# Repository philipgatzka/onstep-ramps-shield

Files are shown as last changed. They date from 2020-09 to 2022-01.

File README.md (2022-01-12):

# onstep-ramps-shield

This is an add-on board for a RAMPSv1.4 (and some later versions) board, which
carries a bit of additional hardware necessary for an
[OnStep](https://github.com/hjd1964/OnStep)
telescope controller.

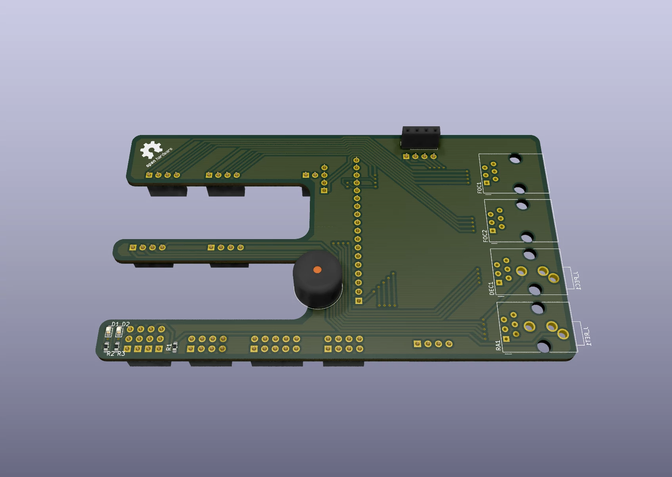
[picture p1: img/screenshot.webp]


There are different ways to build an OnStep, including using a completely custom
board, but I liked the modular approach and used an Arduino Mega in combination
with a RAMPS shield. The custom boards of course offer places to fit connectors
and such which the Arduino/RAMPS combination doesn't, so I'm trying to build
this board to help with that.

At the moment, the board takes the following components:
- RA motor connector, RJ12 6p6c
- DEC motor connector, RJ12 6p6c
- Focuser motor 1 connector, RJ12 6p6c
- Focuser motor 2 connector, RJ12 6p6c
- (Polar alignment scope illuminator connector, 3-Pin 3.5mm audio jack)
- (PEC sensor connector, 3-Pin 3.5mm audio jack)
- Buzzer
- DS3231 RTC via I2C
- BME280 environmental sensor via I2C
- HC05 Bluetooth module via Serial

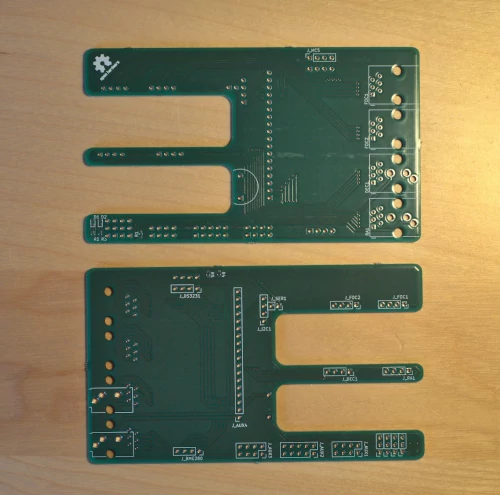
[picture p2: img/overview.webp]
overview


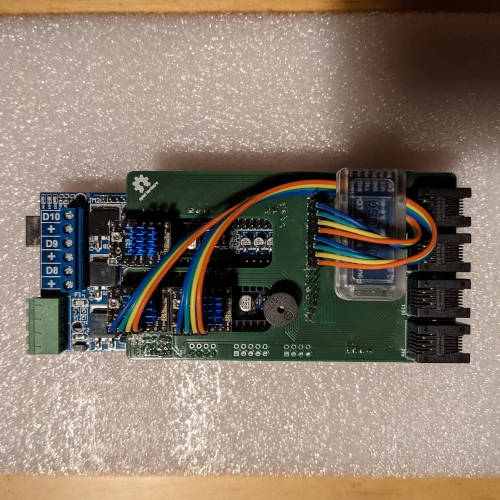
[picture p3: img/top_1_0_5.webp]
top_1_0_5


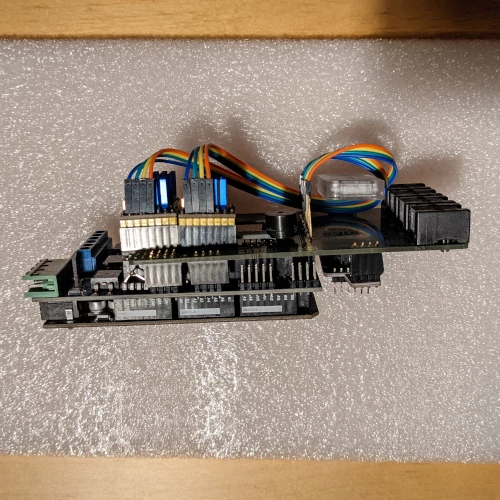
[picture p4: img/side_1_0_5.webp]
side_1_0_5


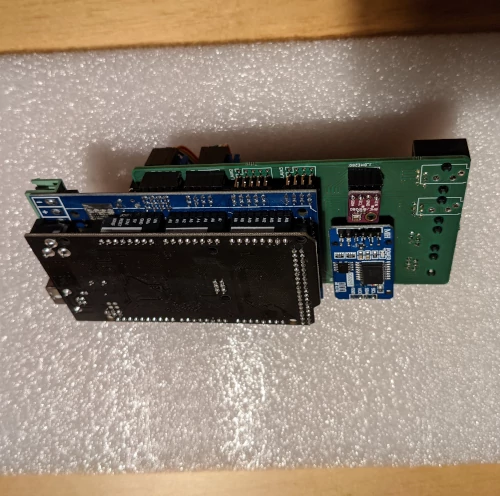
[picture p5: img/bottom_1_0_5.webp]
bottom_1_0_5


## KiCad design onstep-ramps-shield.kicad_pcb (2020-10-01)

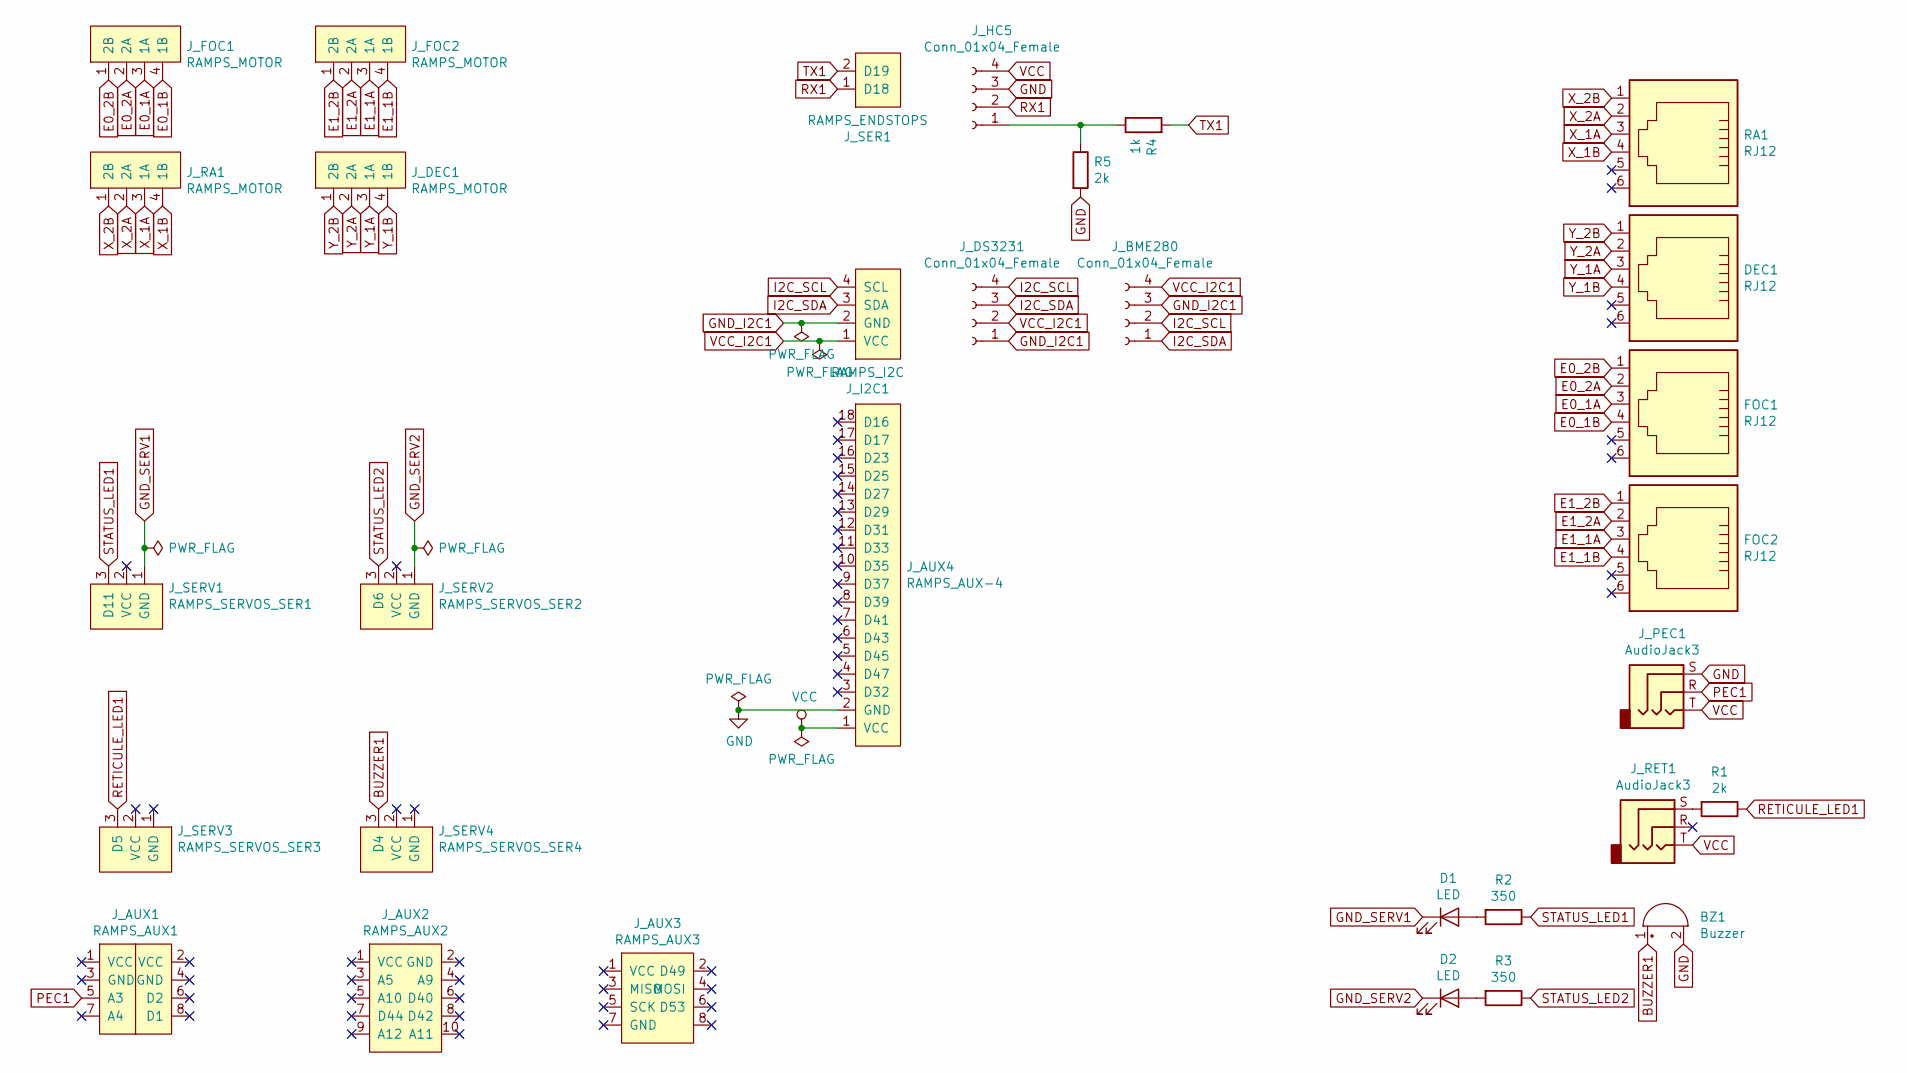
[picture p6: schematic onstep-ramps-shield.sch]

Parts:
BZ1: Buzzer; Buzzer_12x9.5RM7.6
D1, D2: LED; LED_0603_1608Metric_Pad1.05x0.95mm_HandSolder
DEC1: RJ12; RJ12_Amphenol_54601
FOC1, FOC2: RJ12; RJ12_Amphenol_54601
J_AUX1: RAMPS_AUX1; PinSocket_2x04_P2.54mm_Vertical
J_AUX2: RAMPS_AUX2; PinSocket_2x05_P2.54mm_Vertical
J_AUX3: RAMPS_AUX3; PinSocket_2x04_P2.54mm_Vertical
J_AUX4: RAMPS_AUX-4; PinSocket_1x18_P2.54mm_Vertical
J_BME280: Conn_01x04_Female; PinSocket_1x04_P2.54mm_Vertical
J_DEC1: RAMPS_MOTOR; PinSocket_1x04_P2.54mm_Vertical
J_DS3231: Conn_01x04_Female; PinSocket_1x04_P2.54mm_Vertical
J_FOC1, J_FOC2: RAMPS_MOTOR; PinSocket_1x04_P2.54mm_Vertical
J_HC5: Conn_01x04_Female; PinSocket_1x04_P2.54mm_Vertical
J_I2C1: RAMPS_I2C; PinSocket_1x04_P2.54mm_Vertical
J_PEC1: AudioJack3; Jack_3.5mm_CUI_SJ1-3533NG_Horizontal_CircularHoles
J_RA1: RAMPS_MOTOR; PinSocket_1x04_P2.54mm_Vertical
J_RET1: AudioJack3; Jack_3.5mm_CUI_SJ1-3533NG_Horizontal_CircularHoles
J_SER1: RAMPS_ENDSTOPS; PinSocket_1x02_P2.54mm_Vertical
J_SERV1: RAMPS_SERVOS_SER1; PinSocket_1x03_P2.54mm_Vertical
J_SERV2: RAMPS_SERVOS_SER2; PinSocket_1x03_P2.54mm_Vertical
J_SERV3: RAMPS_SERVOS_SER3; PinSocket_1x03_P2.54mm_Vertical
J_SERV4: RAMPS_SERVOS_SER4; PinSocket_1x03_P2.54mm_Vertical
R1, R5: 2k; R_0603_1608Metric_Pad1.05x0.95mm_HandSolder
R2, R3: 350; R_0603_1608Metric_Pad1.05x0.95mm_HandSolder
R4: 1k; R_0603_1608Metric_Pad1.05x0.95mm_HandSolder
RA1: RJ12; RJ12_Amphenol_54601

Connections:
BUZZER1: BZ1.1 (-), J_SERV4.3 (D4)
E0_1A: FOC1.3, J_FOC1.3 (1A)
E0_1B: FOC1.4, J_FOC1.4 (1B)
E0_2A: FOC1.2, J_FOC1.2 (2A)
E0_2B: FOC1.1, J_FOC1.1 (2B)
E1_1A: FOC2.3, J_FOC2.3 (1A)
E1_1B: FOC2.4, J_FOC2.4 (1B)
E1_2A: FOC2.2, J_FOC2.2 (2A)
E1_2B: FOC2.1, J_FOC2.1 (2B)
GND: BZ1.2 (+), J_AUX4.2 (GND), J_HC5.3, J_PEC1.S, R5.2
GND_I2C1: J_BME280.3, J_DS3231.1, J_I2C1.2 (GND)
GND_SERV1: D1.1 (K), J_SERV1.1 (GND)
GND_SERV2: D2.1 (K), J_SERV2.1 (GND)
I2C_SCL: J_BME280.2, J_DS3231.4, J_I2C1.4 (SCL)
I2C_SDA: J_BME280.1, J_DS3231.3, J_I2C1.3 (SDA)
unnamed: D1.2 (A), R2.2
unnamed: D2.2 (A), R3.2
unnamed: J_HC5.1, R4.1, R5.1
unnamed: J_RET1.S, R1.2
PEC1: J_AUX1.5 (A3), J_PEC1.R
RETICULE_LED1: J_SERV3.3 (D5), R1.1
RX1: J_HC5.2, J_SER1.1 (D18)
STATUS_LED1: J_SERV1.3 (D11), R2.1
STATUS_LED2: J_SERV2.3 (D6), R3.1
TX1: J_SER1.2 (D19), R4.2
VCC: J_AUX4.1 (VCC), J_HC5.4, J_PEC1.T, J_RET1.T
VCC_I2C1: J_BME280.4, J_DS3231.2, J_I2C1.1 (VCC)
X_1A: J_RA1.3 (1A), RA1.3
X_1B: J_RA1.4 (1B), RA1.4
X_2A: J_RA1.2 (2A), RA1.2
X_2B: J_RA1.1 (2B), RA1.1
Y_1A: DEC1.3, J_DEC1.3 (1A)
Y_1B: DEC1.4, J_DEC1.4 (1B)
Y_2A: DEC1.2, J_DEC1.2 (2A)
Y_2B: DEC1.1, J_DEC1.1 (2B)

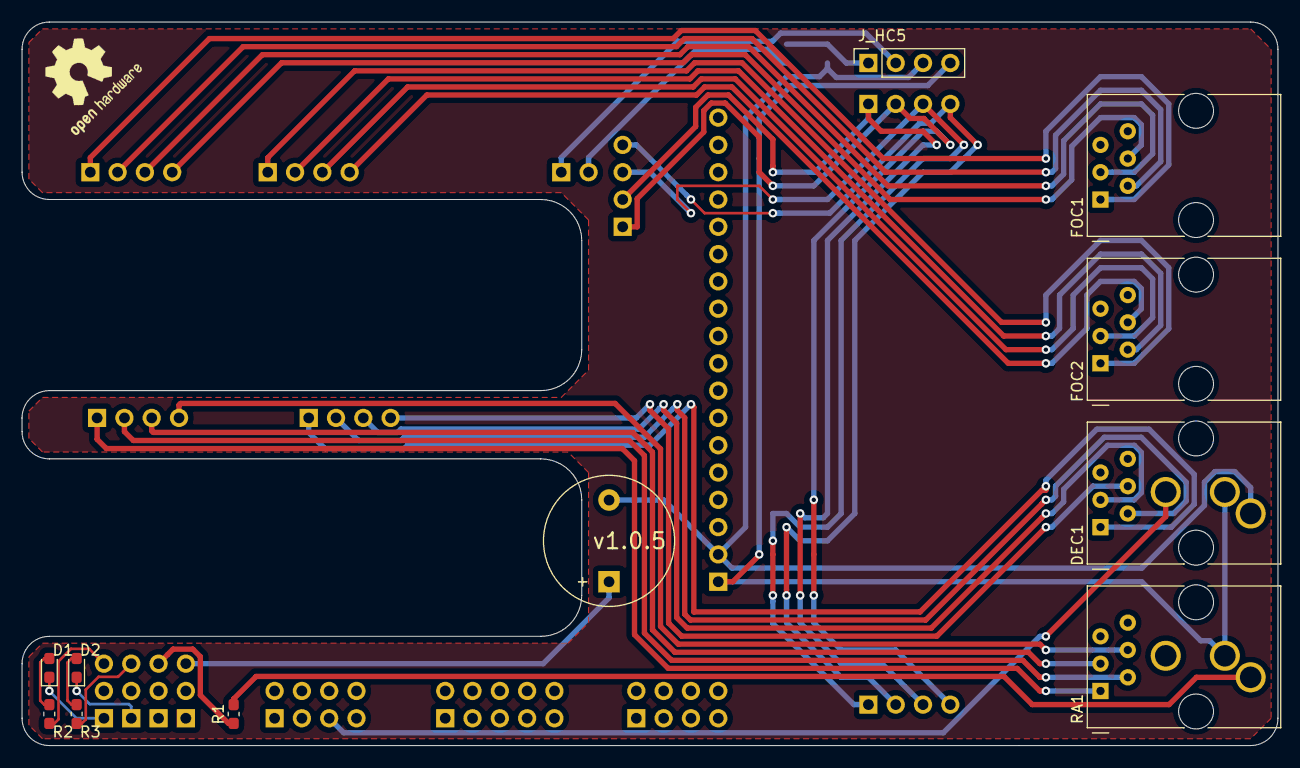
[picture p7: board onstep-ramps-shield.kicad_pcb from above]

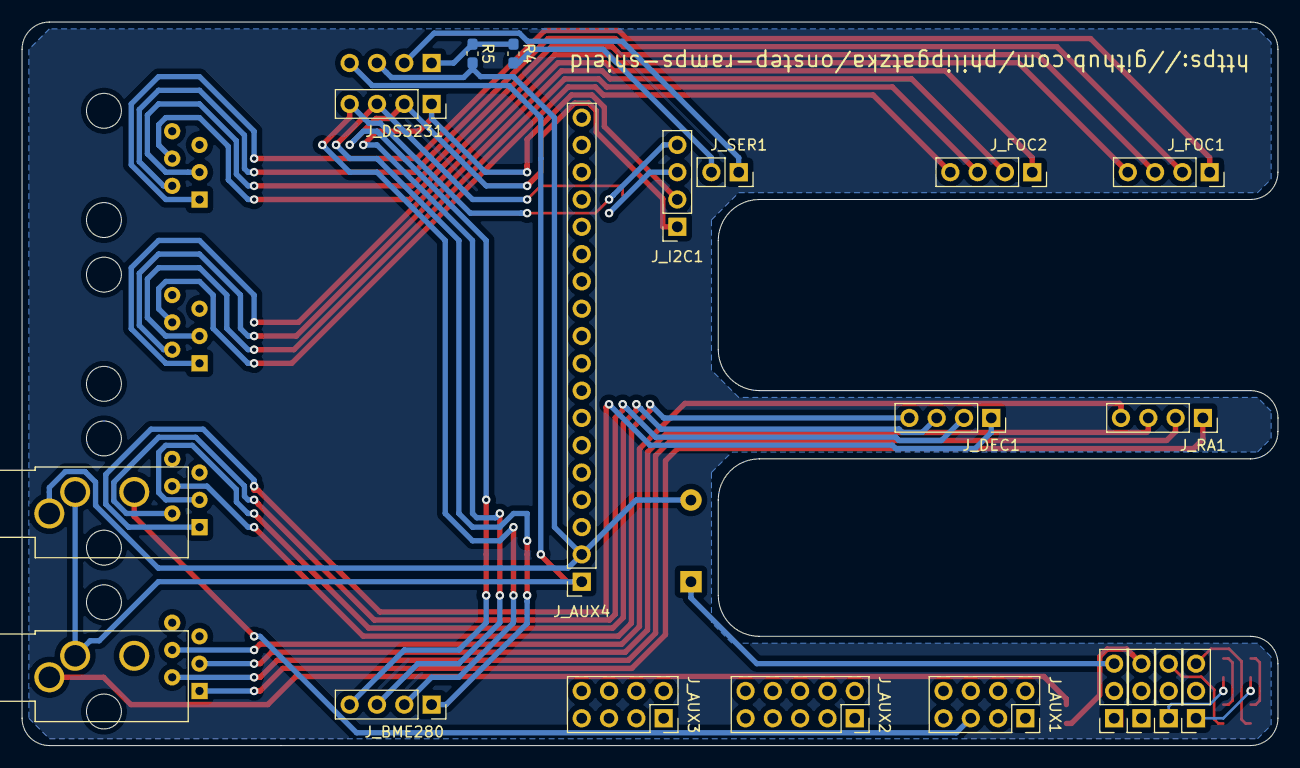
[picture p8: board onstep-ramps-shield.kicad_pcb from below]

Board: 2 copper layers, 116.8 x 67.3 mm, 31 parts (20 on the bottom side), 35 nets.

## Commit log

2020-08-31 KiCad init
    [onstep-ramps-shield.kicad_pcb, onstep-ramps-shield.sch]
2020-08-31 Add RAMPS connectors to project library
2020-08-31 Schematic, initial board layout
    [onstep-ramps-shield.kicad_pcb, onstep-ramps-shield.sch]
2020-08-31 WIP - Routing
    [onstep-ramps-shield.kicad_pcb]
2020-09-03 Include HC05
    [onstep-ramps-shield.kicad_pcb, onstep-ramps-shield.sch]
2020-09-05 Measured distances
    [onstep-ramps-shield.kicad_pcb]
2020-09-05 Reorder components
    [onstep-ramps-shield.kicad_pcb, onstep-ramps-shield.sch]
2020-09-05 Copper fill
    [onstep-ramps-shield.kicad_pcb]
2020-09-05 Increase inner corner radius
    [onstep-ramps-shield.kicad_pcb]
2020-09-05 Remove gerbers
    [onstep-ramps-shield-B_Mask.gbr, onstep-ramps-shield-B_Paste.gbr, onstep-ramps-shield-B_SilkS.gbr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]
2020-09-05 Add .gitignore for gerber files
2020-09-05 Update connectors
    [onstep-ramps-shield.kicad_pcb, onstep-ramps-shield.sch]
2020-09-05 Add voltage divider for HC05
    [onstep-ramps-shield.kicad_pcb, onstep-ramps-shield.sch]
2020-09-05 Re-route R4 trace
    [onstep-ramps-shield.kicad_pcb]
2020-09-05 Rearrange resistors
    [onstep-ramps-shield.kicad_pcb, onstep-ramps-shield.sch]
2020-09-06 Increase trace to edge distance for LEDs
    [onstep-ramps-shield.kicad_pcb]
2020-09-17 Increased connector distance
    [onstep-ramps-shield.kicad_pcb]
2020-09-17 Add silkscreen version info
    [onstep-ramps-shield.kicad_pcb]
2020-10-01 Update distances
    [onstep-ramps-shield.kicad_pcb]
